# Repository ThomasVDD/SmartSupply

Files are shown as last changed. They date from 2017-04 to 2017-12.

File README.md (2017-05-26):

# SmartSupply
SmartSupply is a digital battery powered lab powersupply. It is Arduino compatible and can be controlled via PC over USB.

## Specifications:
 * 0 - 1A,  steps of 1 mA  (10 bit DAC)
 * 0 - 20V, steps of 20 mV (10 bit DAC) (true 0V operation)
 * Voltage measurement: 20 mV resolution (10 bit ADC)
 * Current measurement: 
      -     < 40mA:  10uA resolution (ina219)
 			< 80mA:  20uA resolution (ina219)
 			< 160mA: 40uA resolution (ina219)
			< 320mA: 80uA resolution (ina219)
			> 320mA: 1mA  resolution (10 bit ADC)

## Features: 
 * Constant voltage and constant current modes
 * Uses a low noise linear regulator, preceded by a tracking preregulator to minimize power dissipation
 * Aluminium case end panel used as heatsink 
 * Use of handsolderable components to keep the project accessible 
 * Powered by ATMEGA328P, programmed with Arduino IDE
 * PC communication via Java application over micro usb
 * Powered by 2 protected 18650 Lithium Ion cells
 * 19 mm spaced banana plugs for compatibility with BNC adapters

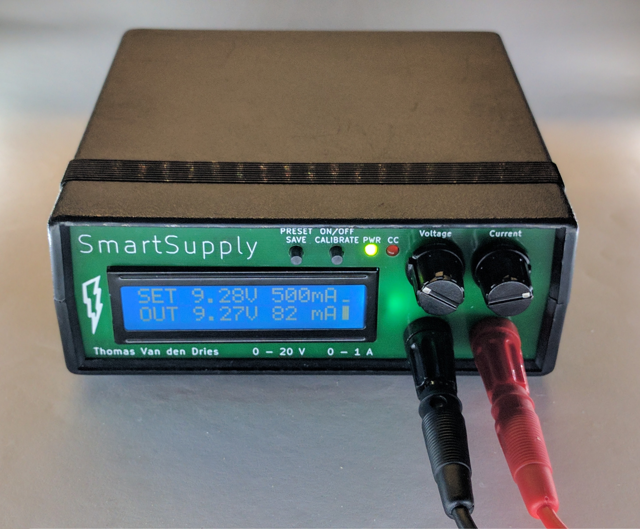
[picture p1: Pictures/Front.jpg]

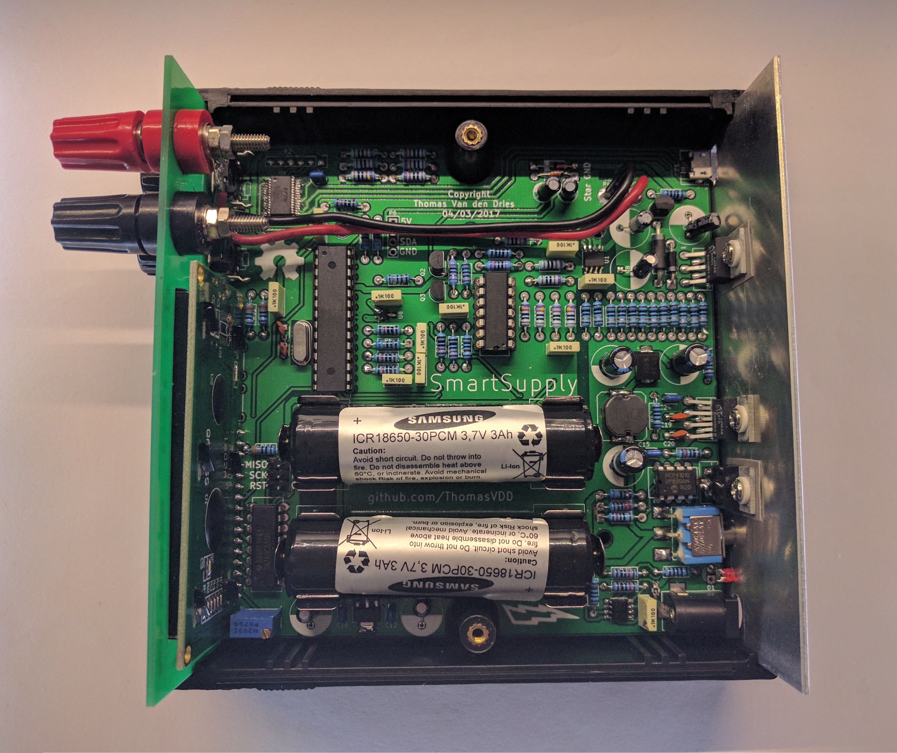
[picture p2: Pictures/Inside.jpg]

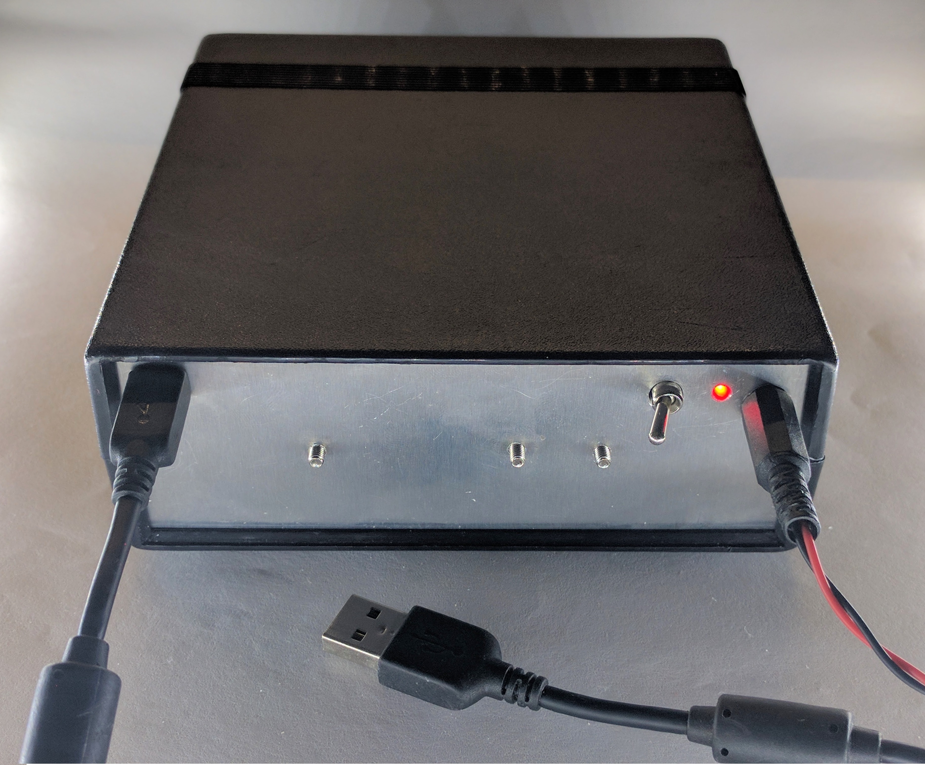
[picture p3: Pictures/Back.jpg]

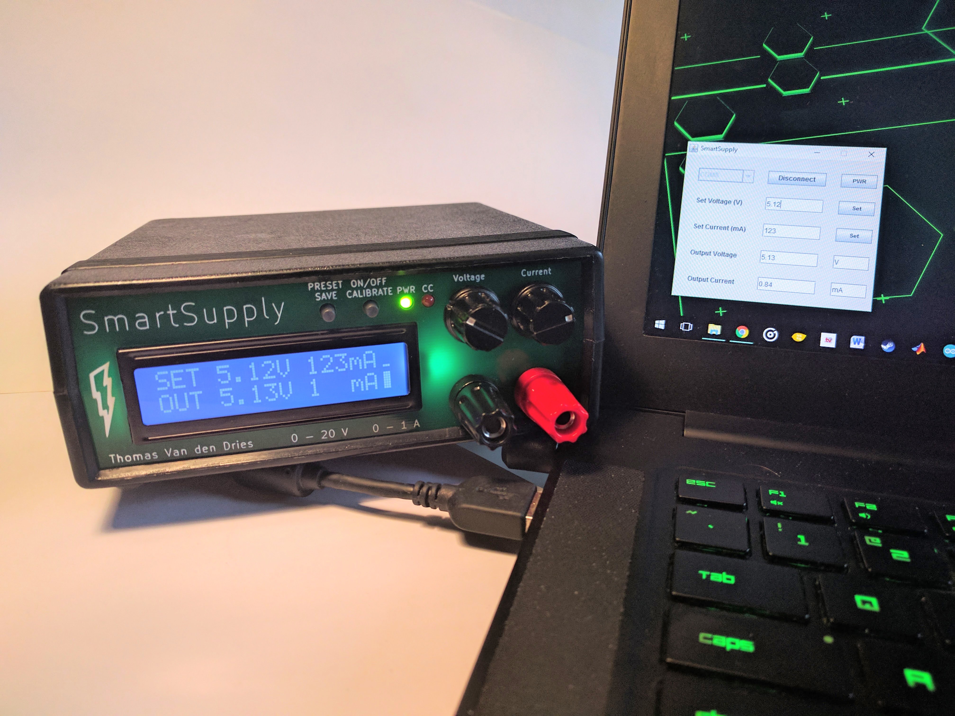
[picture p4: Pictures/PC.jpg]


## Theory of operation: 

To understand the operation of the circuit, we will have to look at the schematic. I divided it into functional blocks, such that it is easier to understand; I will thus also explain the operation step by step. 

### Main block
The operation is based around the LT3080 chip: it's a linear voltage regulator, which can step down voltages, based on a control signal. This control signal will be generated by a microcontroller; how this is done, will be explained in detail later. 

#### Voltage setting
The circuitry around the LT3080 generates the appropriate control signals. First, we will take a look at how the voltage is set. 
The voltage setting from the microcontroller is a PWM signal (PWM_Vset), which is filtered by a lowpass filter (C9 & R26). This produces an analog voltage - between 0 and 5 V - proportional to the wanted output voltage. Since our output range is 0 - 20 V, we will have to amplify this signal with a factor of 4. This is done by the non inverting opamp configuration of U3C. The gain to the set pin is determined by R23//R24//R25 and R34. These resistors are 0.1% tolerant, to minimize errors. R39 and R36 don't matter here, as they are part of the feedback loop.

#### Current setting
This set pin can also be used for the second setting: current mode. We want to measure the current draw, and turn the output off when this exceeds the wanted current. Therefore, we start again by a PWM signal (PWM_Iset), generated by the microcontroller, which is now lowpass filtered and attenuated to go from a 0 - 5 V range to a 0 - 2 V range. This voltage is now compared to the voltage drop across the current sense resistor (ADC_Iout, see below) by the comparator configuration of opamp U3D. If the current is too high, this will turn on an led, and also pull the set line of the LT3080 to ground (via Q2), thus turning off the output.

The measurement of the current, and the generation of the signal ADC_Iout is done as follows. The output current flows through resistors R7 - R16. These total 1 ohm; the reason for not using 1R in the first place is twofold: 1 resistor would need to have a higher power rating (it needs to dissipate at least 1 W), and by using 10 1% resistors in parallel, we get a higher precision than with a single 1 % resistor. A good video about why this works can be found here: https://www.youtube.com/watch?v=1WAhTdWErrU&t=1s
When current flows through these resistors, it creates a voltage drop, which we can measure, and it is placed before the LT3080, since the voltage drop across it should not influence the output voltage. 
The voltage drop is measured with a differential amplifier (U3B) with a gain of 2. This results in a voltage range of 0 - 2 V (more on that later), hence the voltage divider at the PWM signal of the current. The buffer (U3A) is there to make sure that the current flowing into resistors R21, R32 and R33 is not going through the current sense resistor, which would influence it's reading. 
Also note that this should be a rail-to-rail opamp, because the input voltage at the positive input equals the supply voltage. 

The non inverting amplifier is only for the course measurement though, for very precise measurements, we have the INA219 chip on board. This chip allows us to measure very small currents, and is addressed via I2C. 

#### Additional things
At the output of the LT3080, we have some more stuff. First of all, there is a current sink (LM334). This draws a constant current of 677 uA (set by resistor R41), to stabilize the LT3080. It is however not connected to ground, but to VEE, a negative voltage. This is needed to allow the LT3080 to operate down to 0 V. When connected to ground, the lowest voltage would be about 0.7 V. This seems low enough, but keep in mind that this prevents us from turning the powersupply completely off. 
The zener diode D3 is used to clamp the output voltage if it goes above 22 V, and the resistor divider drops the output voltage range from 0 - 20 V to 0 - 2 V (ADC_Vout). 
Unfortunately, these circuits are at the output off the LT3080, which means their current will contribute to the output current we want to measure. Fortunately, these currents are constant if the voltage stays constant; so we can calibrate the current when the load is disconnected first. 

### Charge pump
The negative voltage that we mentioned before is generated by a curious little circuit: the charge pump. For it's operation, I would refer to here: https://www.youtube.com/watch?v=LtoPHevexTM&t=2s It is fed by a 50% PWM of the microcontroller (PWM)

### Boost Converter
Let's now take a look at the input voltage of our main block: Vboost. We see that it is 8 - 24V, but wait, 2 lithium cells in series gives a maximum of 8.4 V? Indeed, and that's why we need to boost the voltage, with a so called boost converter. We could always boost the voltage to 24 V, no matter what output we want; however, this would waste a lot of power in the LT3080 and things would get toasty hot! So instead of doing that, we will boost the voltage to a bit more than the output voltage. About 2.5 V higher is appropriate, to account for the voltage drop in the current sense resistor and the dropout voltage of the LT3080. 
The voltage is set by resistors on the output signal of the boost converter. To change this voltage on the fly, we use a digital potentiometer, the MCP41010, which is controlled via SPI. 

### Battery Charging
This leads us to the real input voltage: the batteries! Since we use protected cells, we simply need to put them in series and we're done! It is important to use protected cells here, to avoid overcurrent or overdischarge, and thus damaging, of the cells. 
Again, we use a voltage divider for measuring the battery voltage, and dropping it down to a usable range.
Now on to the interesting part: the charging circuitry. We use the BQ2057WSN chip for this purpose: in combination with the TIP32CG, it basically forms a linear powersupply itself. This chip charges the cells via an appropriate CV CC trajectory. Since my batteries don't have a temperature probe, this input should be tied to half the battery voltage. This concludes the voltage regulation part of the powersupply. 

### 5V regulator
The 5 V supply voltage of the arduino is made with this simple voltage regulator. It is not the most precise 5 V output however, but this will be solved below. 

### 2.048 V voltage reference
This little chip provides a very accurate 2.048 V voltage reference. This is used as a reference for the analog signals ADC_Vout, ADC_Iout, ADC_Vbatt. That's why we needed voltage dividers to bring these signals down to 2 V. 

### Microcontroller
The brain of this project is the ATMEGA328P, this is the same chip that is used in the Arduino Uno. We already went over most control signals, but there are some interesting additions nonetheless. The rotary encoders are connected to the 2 only external interrupt pins of the arduino: PD2 and PD3. This is needed for a reliable software implementation. The switches underneath use an internal pullup resistor. 
Then there is this strange voltage divider on the chip select line of the potentiometer (Pot). A voltage divider on an output, what's that good for; you might say. As mentioned before, the 5 V supply is not teribbly accurate. It would thus be good to measure this accurately, and adjust the duty cycle of the PWM signal accordingly. But since I had no more free inputs, I had to make a pin pull double duty. When the powersupply boots, this pin is first set as an input: it measures the supply rail and calibrates itself. Next, it is set as an output and it can drive the chip select line. 

### Display Driver
For the display, I wanted a commonly available - and cheap - hitachi lcd screen. They are driven by 6 pins, but since I had no pins left, I needed another solution. A shift register to the rescue! The 74HC595 allows me to use the SPI line to control the display, thus only needing 1 additional chip select line. 

### FTDI
The last part of this powersupply is the connection with the cruel, outside world. For this, we need to convert the serial signals into USB signals. This is done by an FTDI chip, which is connected to a micro USB port for easy connection.

And that's all there is to it! 

## Licensing and acknowledgements

License

This project would never have been possible without the help of some people, so a shootout seems appropriate.
 * This project is based on EEVBLOG's uSupply project and his Rev C schematic. So a special thanks to David L. Jones for releasing his schematics under an open source license and sharing all his knowledge.
 * A huge thanks to Johan Pattyn for producing the prototypes of this project. 
 * Also Cedric Busschots and Hans Ingelberts deserve credit for the help with troubleshooting.

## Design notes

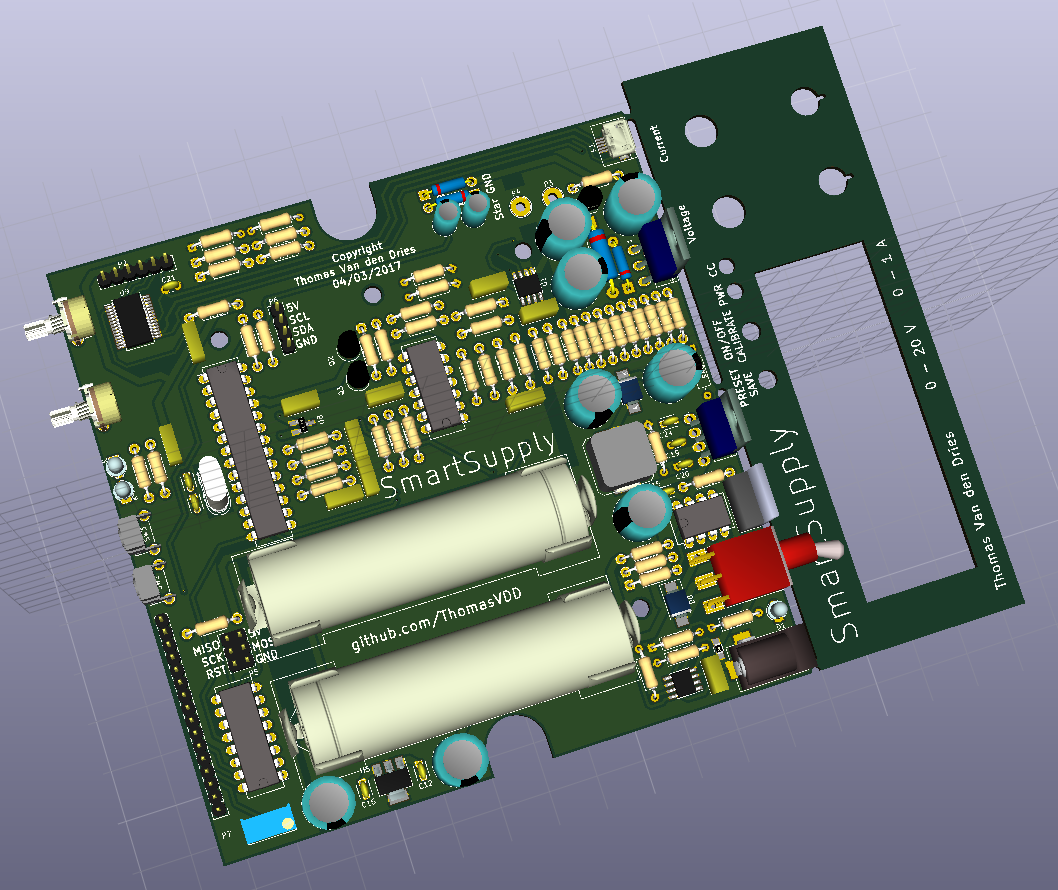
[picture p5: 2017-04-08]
Pictures/3D.PNG

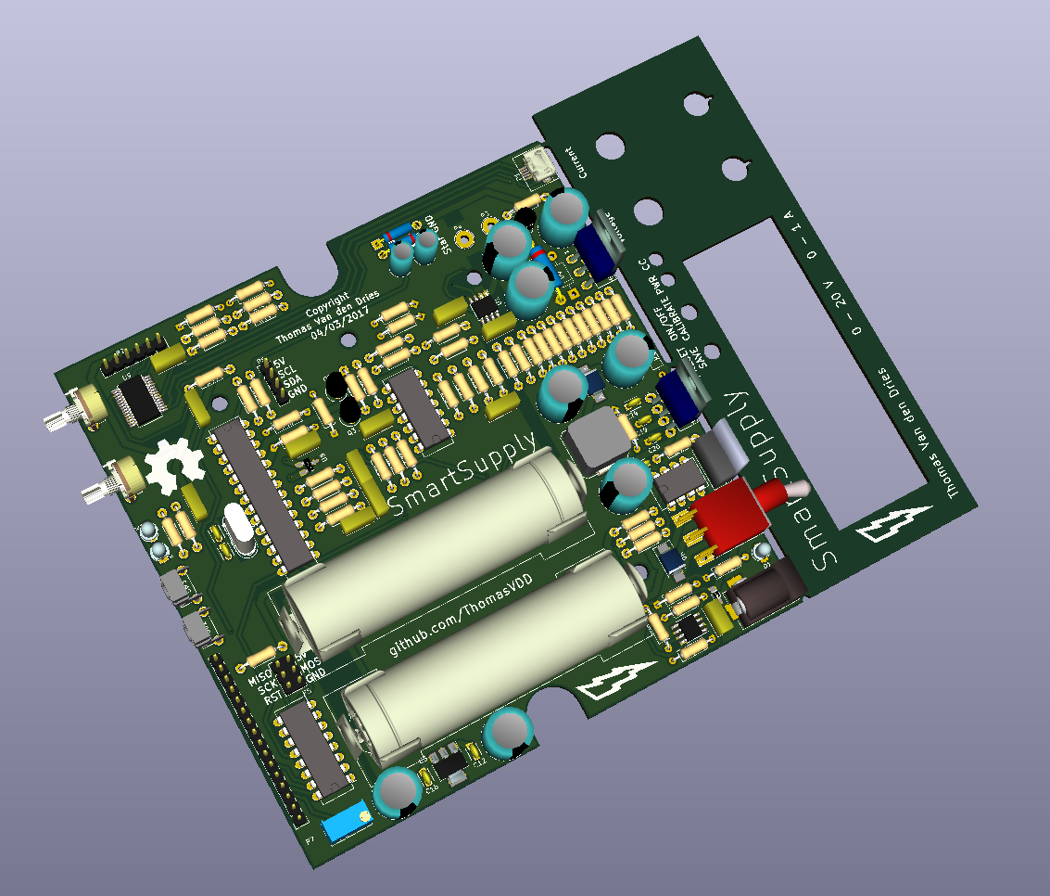
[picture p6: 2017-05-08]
PCB/3D.PNG

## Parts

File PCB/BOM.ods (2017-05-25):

Id | Designator | Package | Quantity | Designation | Supplier and ref | Price | Total | No_Battery | No_battery | Aliexpress
1 | R1,R2,R7,R8,R9,R10,R11,R12,R13,R14,R15,R16 | Resistor_Horizontal_RM10mm | 12 | 10R |  |  | 0 | 1 | 0
2 | R6,R18,R31,R36,R42 | Resistor_Horizontal_RM10mm | 5 | 1k |  |  | 0 | 1 | 0
3 | R27,R5,R53,R54 | Resistor_Horizontal_RM10mm | 4 | 6k8 |  |  | 0 | 1 | 0
4 | R28,R48 | Resistor_Horizontal_RM10mm | 2 | 2.2k |  |  | 0 | 1 | 0
5 | R3,R17,R19,R20,R26,R35,R37,R38,R51,R55 | Resistor_Horizontal_RM10mm | 10 | 10k |  |  | 0 | 1 | 0
6 | R52,R56,R40 | Resistor_Horizontal_RM10mm | 3 | 330R |  |  | 0 | 1 | 0
7 | R39,R41 | Resistor_Horizontal_RM10mm | 2 | 100R |  |  | 0 | 1 | 0
8 | R50 | Resistor_Horizontal_RM10mm | 1 | 620R |  |  | 0 | 1 | 0
9 | R34,R21,R22,R25,R29,R30,R32,R33,R43,R44,R45,R47,R23,R24,R46,R49, R57, R58, R59 | Resistor_Horizontal_RM10mm | 19 | 10k 0.1% | 1083362 | 0.711 | 13.509 | 1 | 13.509 | 7
10 | R4 | R_0805_HandSoldering | 1 | 0.2R | 2493030 | 0.335 | 0.335 | 0 | 0 | 0.335
11 | RV1 | Potentiometer_Bourns_3296W_3-8Zoll_Inline_ScrewUp | 1 | POT | 1141404 | 1.49 | 1.49 | 1 | 1.49 | 0.1
12 | C1,C3,C6,C7,C9,C22,C29,C2,C5,C10,C21,C23 | C_Rect_L7_W2.5_P5 | 12 | 100n |  |  | 0 | 1 | 0
13 | C13,C4,C25 | C_Radial_D10_L13_P5 | 3 | 220u |  |  | 0 | 1 | 0
14 | C24,C15,C12,C16 | C_Disc_D3_P2.5 | 4 | 10n |  |  | 0 | 1 | 0
16 | C26,C27 | C_Disc_D3_P2.5 | 2 | 22p |  |  | 0 | 1 | 0
17 | C14,C11,C18 | C_Radial_D10_L13_P5 | 5 | 22u |  |  | 0 | 1 | 0
18 | C30 | C_Radial_D5_L11_P2.5 | 1 | 100u |  |  | 0 | 1 | 0
19 | C28 | C_Radial_D5_L11_P2.5 | 1 | 22u |  |  | 0 | 1 | 0
20 | C19 | C_Disc_D3.0mm_W1.6mm_P2.50mm | 1 | 47n |  |  | 0 | 1 | 0
21 | C20 | C_Disc_D3.0mm_W1.6mm_P2.50mm | 1 | 4.7n |  |  | 0 | 1 | 0
22 | L1 | SELF-WE-PD-XXL | 1 | 47u | 1864422 | 0.778 | 0.778 | 1 | 0.778 | 0.94138
23 | D1, D2 | LED-3MM | 2 | Red_Led |  |  | 0 | 0 | 0
24 | D3 | D_DO-41_SOD81_P10.16mm_Horizontal | 1 | 1N5358B | 9558160 | 0.381 | 0.381 | 1 | 0.381 | 0.46101
25 | D4,D8 | SMB_Handsoldering | 2 | SS34 | 2677460 | 0.25 | 0.5 | 0 | 0 | 0.5
26 | D5 | LED-3MM | 1 | Green_Led |  |  | 0 | 1 | 0
27 | D6,D7 | Diode_DO-41_SOD81_Horizontal_RM10 | 2 | 1N4148 | 9565124 | 0.0203 | 0.0406 | 1 | 0.0406 | 0.049126
28 | D9 | D_DO-41_SOD81_P10.16mm_Horizontal | 1 | 1N4007 | 1467514 | 0.169 | 0.169 | 1 | 0.169 | 0.20449
29 | U1 | SOIC-8_3.9x4.9mm_Pitch1.27mm | 1 | INA219 | 2496402 | 2.45 | 2.45 | 1 | 2.45 | 2.9645
30 | U2 | SOIC-8_3.9x4.9mm_Pitch1.27mm | 1 | BQ2057WSN_SOIC | 1212263 | 2.2 | 2.2 | 0 | 0 | 1
31 | U3 | DIP-14_W7.62mm_LongPads | 1 | LM6144 | 9493581 | 5.56 | 5.56 | 1 | 5.56 | 6.7276
32 | U4 | Pentawatt_Neutral_Staggered_Verical_TO220-5-T05D | 1 | LT3080 | 2102611 | 4.52 | 4.52 | 1 | 4.52 | 4.52
33 | U5 | SOT-223-3Lead_TabPin2 | 1 | LM7805CT | 2296030 | 0.291 | 0.291 | 1 | 0.291 | 0.291
34 | U6 | TO-92_Inline_Narrow_Oval | 1 | LM334 | 1564650 | 0.784 | 0.784 | 1 | 0.784 | 0.94864
35 | U7 | Pentawatt_Neutral_Staggered_Verical_TO220-5-T05D | 1 | LT1370 | 1273732 | 10.94 | 10.94 | 1 | 10.94 | 2
36 | U8 | SOT-23_Handsoldering | 1 | ISL21070 | 2543327 | 1.57 | 1.57 | 1 | 1.57 | 1.8997
37 | U9 | SSOP-28_5.3x10.2mm_Pitch0.65mm | 1 | FT232R | 1146032 | 4.25 | 4.25 | 1 | 4.25 | 2
38 | U10 | DIP-8_W7.62mm_LongPads | 1 | MCP41010 | 1292242 | 1.28 | 1.28 | 1 | 1.28 | 0.7
39 | U11 | DIP-16_W7.62mm_LongPads | 1 | 74HC595 | 9591664 | 1.18 | 1.18 | 1 | 1.18 | 0.5
40 | IC1 | DIP-28_W7.62mm_LongPads | 1 | ATMEGA328-P | 1715487 | 3.36 | 3.36 | 1 | 3.36 | 1.1
41 | Q1 | SOT-223-3Lead_TabPin2 | 1 | TIP32CG | 1166986 | 0.446 | 0.446 | 0 | 0 | 0.446
42 | Q2,Q3 | TO-92_Inline_Narrow_Oval | 2 | 2N3904 | 1700648 | 0.0762 | 0.1524 | 1 | 0.1524 | 0.1524
43 | P1 | Micro_usb | 1 | USB_OTG | 2293753 | 0.413 | 0.413 | 1 | 0.413 | 0.413
44 | P2 | Pin_Header_Straight_1x06 | 1 | FTDI |  |  | 0 | 1 | 0
45 | P3 | 1pin | 1 | V+ | 2112491 | 2.85 | 2.85 | 1 | 2.85 | 0.5
46 | P4 | 1pin | 1 | V- | 2112490 | 2.85 | 2.85 | 1 | 2.85 | 0.5
47 | P5 | Pin_Header_Straight_2x03 | 1 | ISP |  |  | 0 | 1 | 0
48 | P6 | Pin_Header_Straight_1x04 | 1 | I2C |  |  | 0 | 1 | 0
49 | P7 | Pin_Header_Straight_1x16 | 1 | LCD_Display | aliexpress: https://nl.aliexpress.com/item/Free-shipping-lcd-1602-yellow-green-screen-5V-Character-LCD-Display-Module-yellow-green-Blacklight-New/32333016122.html | 1.12 | 1.12 | 1 | 1.12 | 1.12
50 | SW1 | SW_SPDT | 1 | SWITCH | aliexpress: https://nl.aliexpress.com/item/10-Pcs-2A-250VAC-on-on-2-Way-SPDT-Right-Angle-3-Pins-PCB-Mount-Toggle/32284524869.html | 1.85 | 1.85 | 1 | 1.85 | 1.85
51 | SW2,SW3 | SW_Tactile_SPST_Angled | 2 | SPST | 2402408 | 0.586 | 1.172 | 1 | 1.172 | 0.5
52 | SW4 | Potentiometer_WirePads_Small | 1 | Encoder1 | 2065049 | 0.575 | 0.575 | 1 | 0.575 | 0.69575
53 | SW5 | Potentiometer_WirePads_Small | 1 | Encoder0 | 2065049 | 0.575 | 0.575 | 1 | 0.575 | 0.69575
54 | Y1 | Crystal_HC50-U_Vertical | 1 | 16Mhz | 2508996 | 0.261 | 0.261 | 1 | 0.261 | 0.261
55 | BT2,BT1 | 18650_cell | 4 | Battery | 1888422 | 0.73 | 2.92 | 0 | 0 | 3.5332
56 | CON1 | BARREL_JACK | 1 | BARREL_JACK | 1737246 | 0.789 | 0.789 | 1 | 0.789 | 0.789
 |  | Thermal pad + mica washer | 2 |  | 520214 | 0.231 | 0.462 | 1 | 0.462 | 0.462
 |  | Hammond case with aluminium end panels | 1 |  | 722583 | 12.17 | 12.17 | 1 | 12.17 | 14.7257
 |  | Knobs for rotary encoders | 2 |  | atys | 1.5 | 3 | 1 | 3 | 1
 |  | Protected Lithium cells | 2 |  | http://www.conrad.be/ce/nl/product/1009505/Samsung-ICR18650-30B-Speciale-oplaadbare-batterij-18650-Li-ion-37-V-3000-mAh | 14.79 | 29.58 | 0 | 0 | 29.58
 |  |  |  |  |  |  | Battery |  | No Battery | Aliexpress
 |  |  |  |  |  |  | Total |  | Total | Total
 |  |  |  |  |  |  | 134.45353 |  | 97.12832 | 91.466246

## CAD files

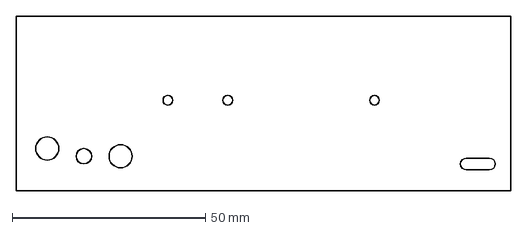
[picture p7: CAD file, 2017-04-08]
BackPanel/BackPanel.dxf
128.0 x 45.3 mm

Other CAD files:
BackPanel/BackPanel.ipt
BackPanel/OldVersions/BackPanel.0002.ipt

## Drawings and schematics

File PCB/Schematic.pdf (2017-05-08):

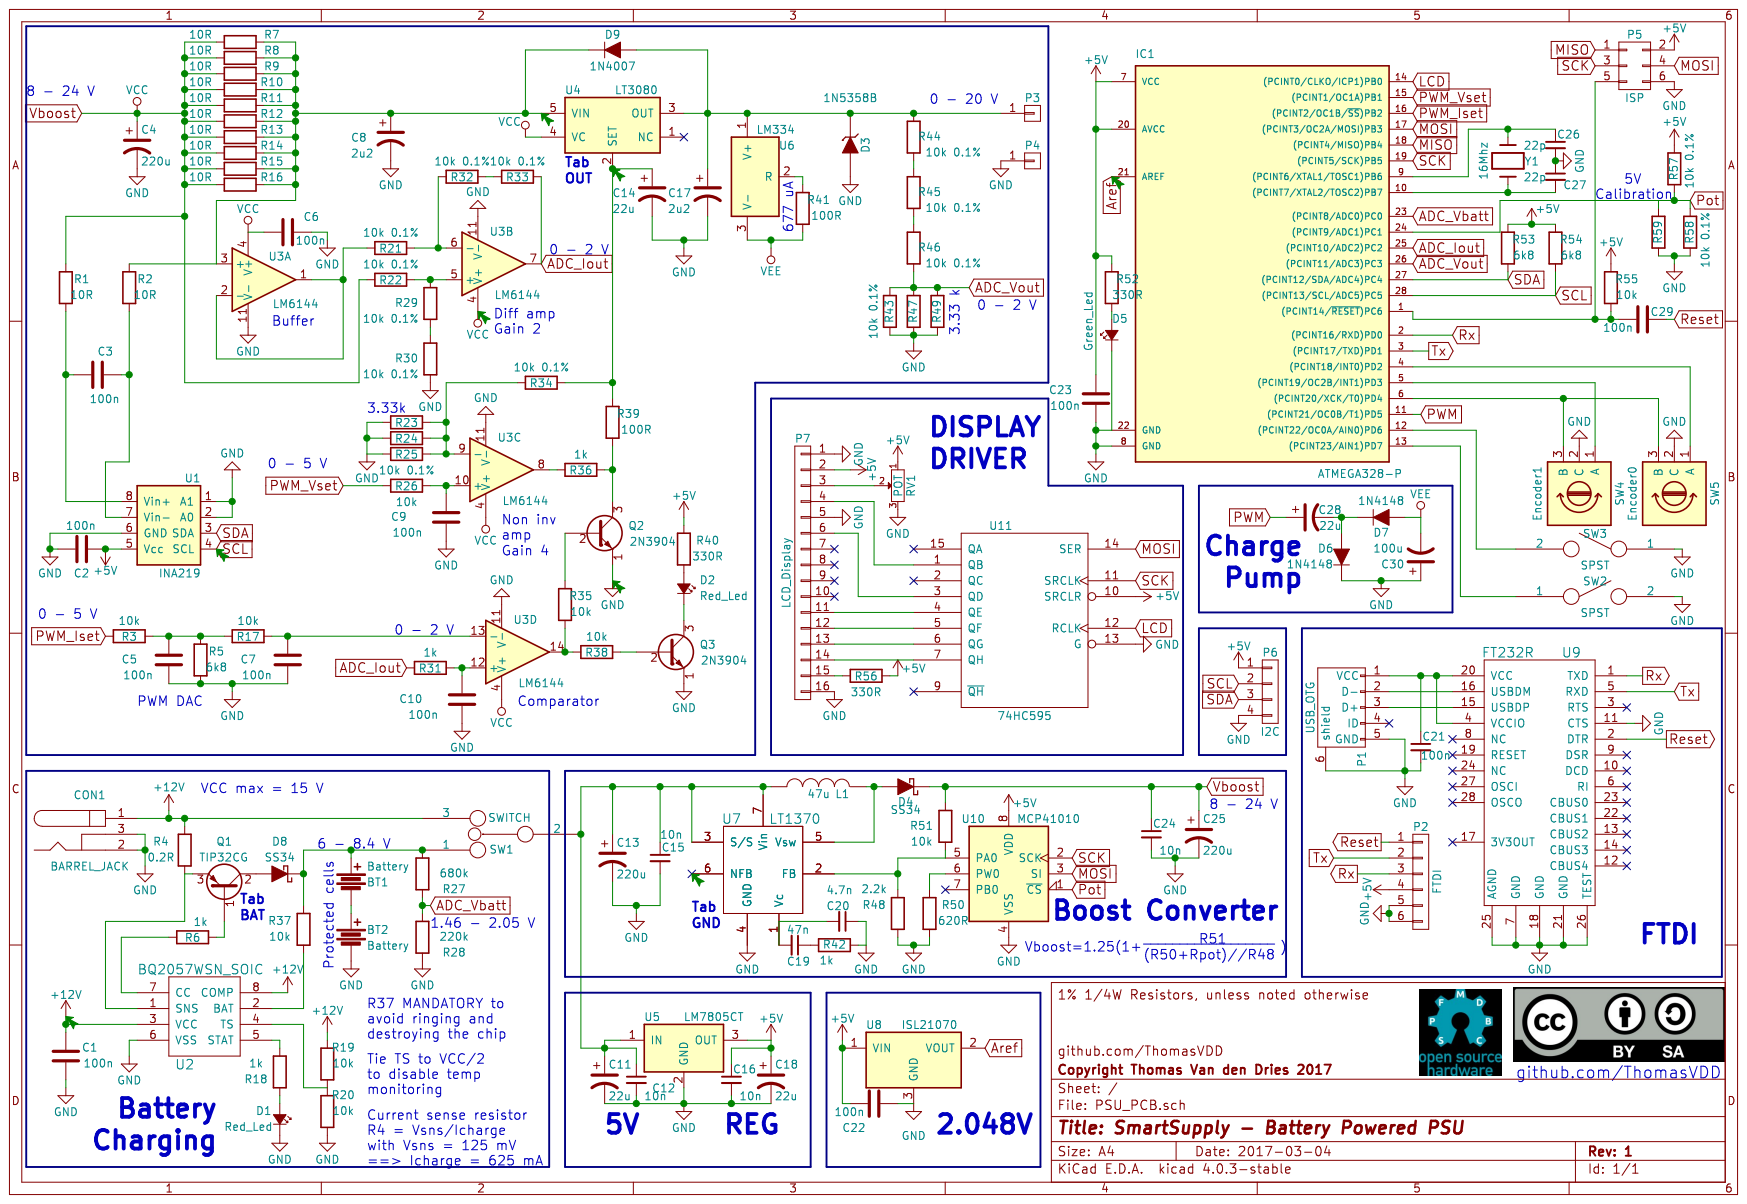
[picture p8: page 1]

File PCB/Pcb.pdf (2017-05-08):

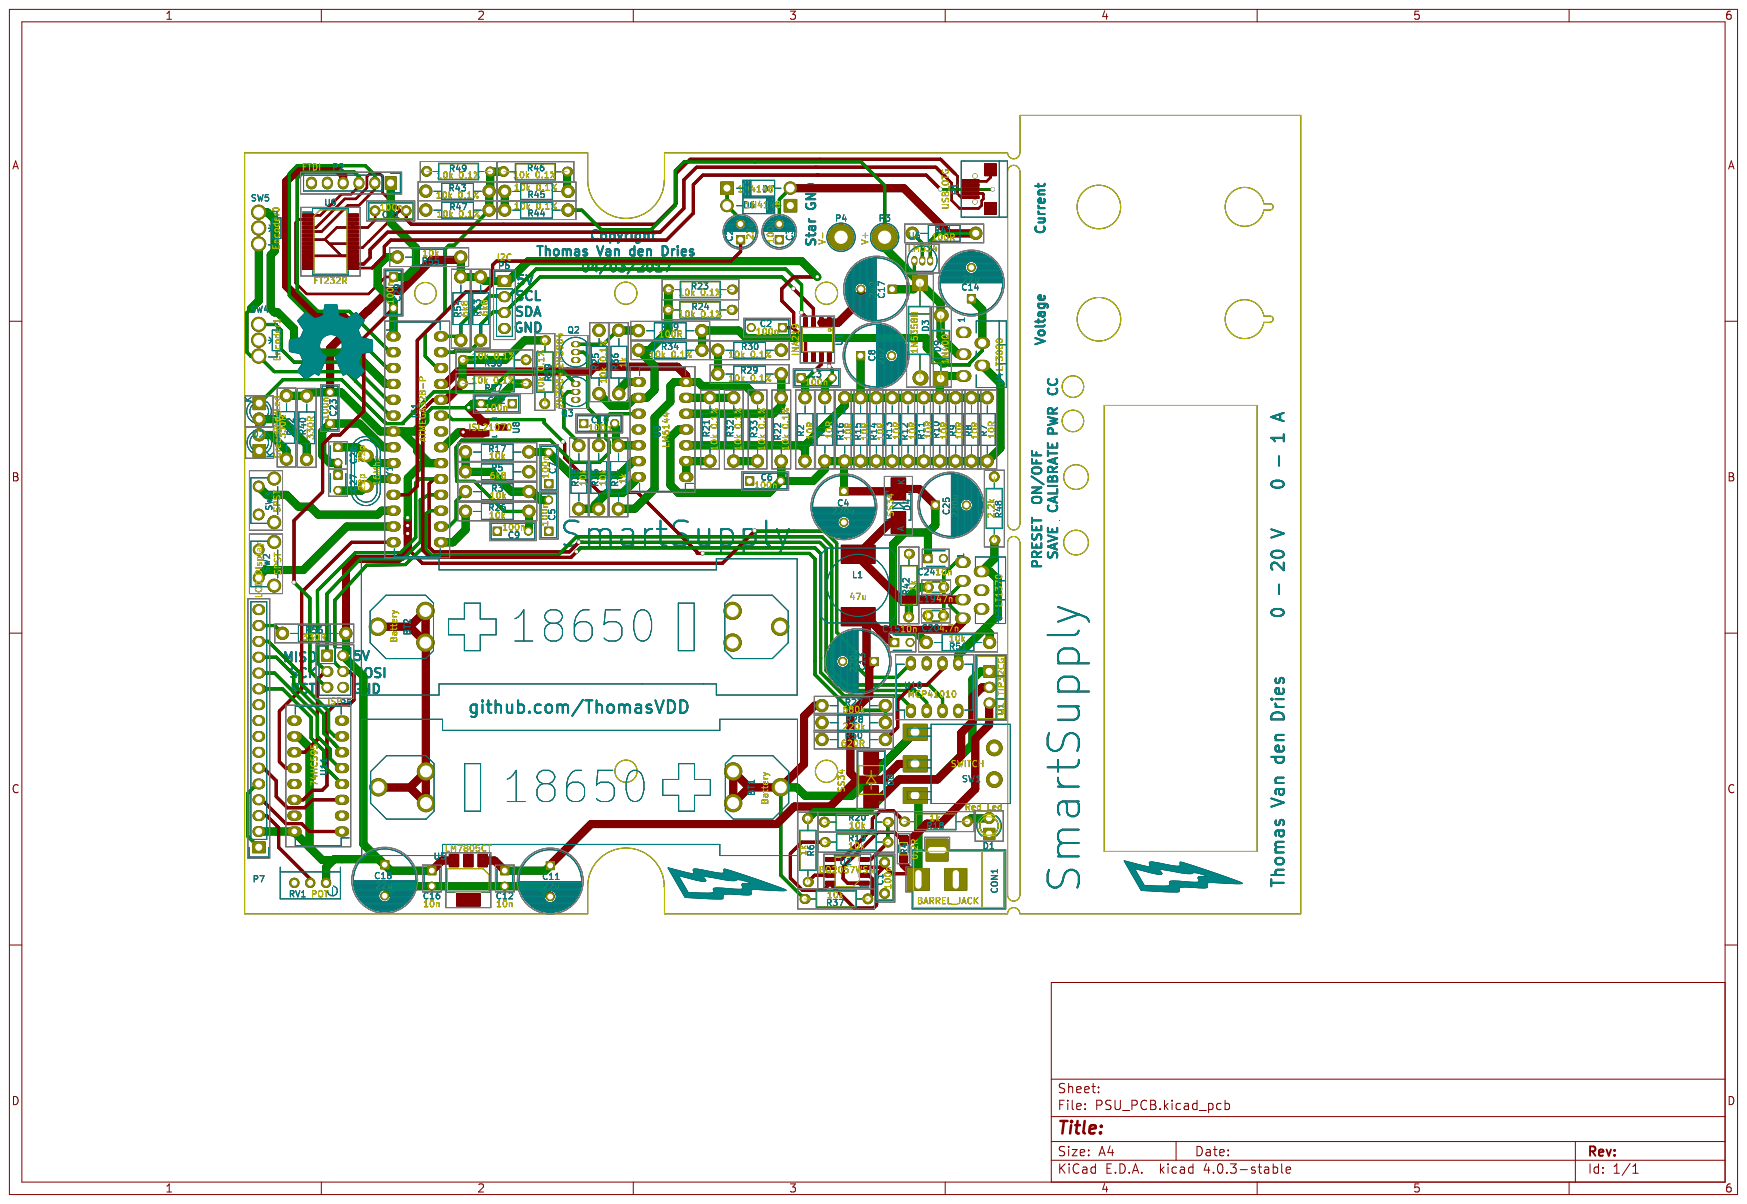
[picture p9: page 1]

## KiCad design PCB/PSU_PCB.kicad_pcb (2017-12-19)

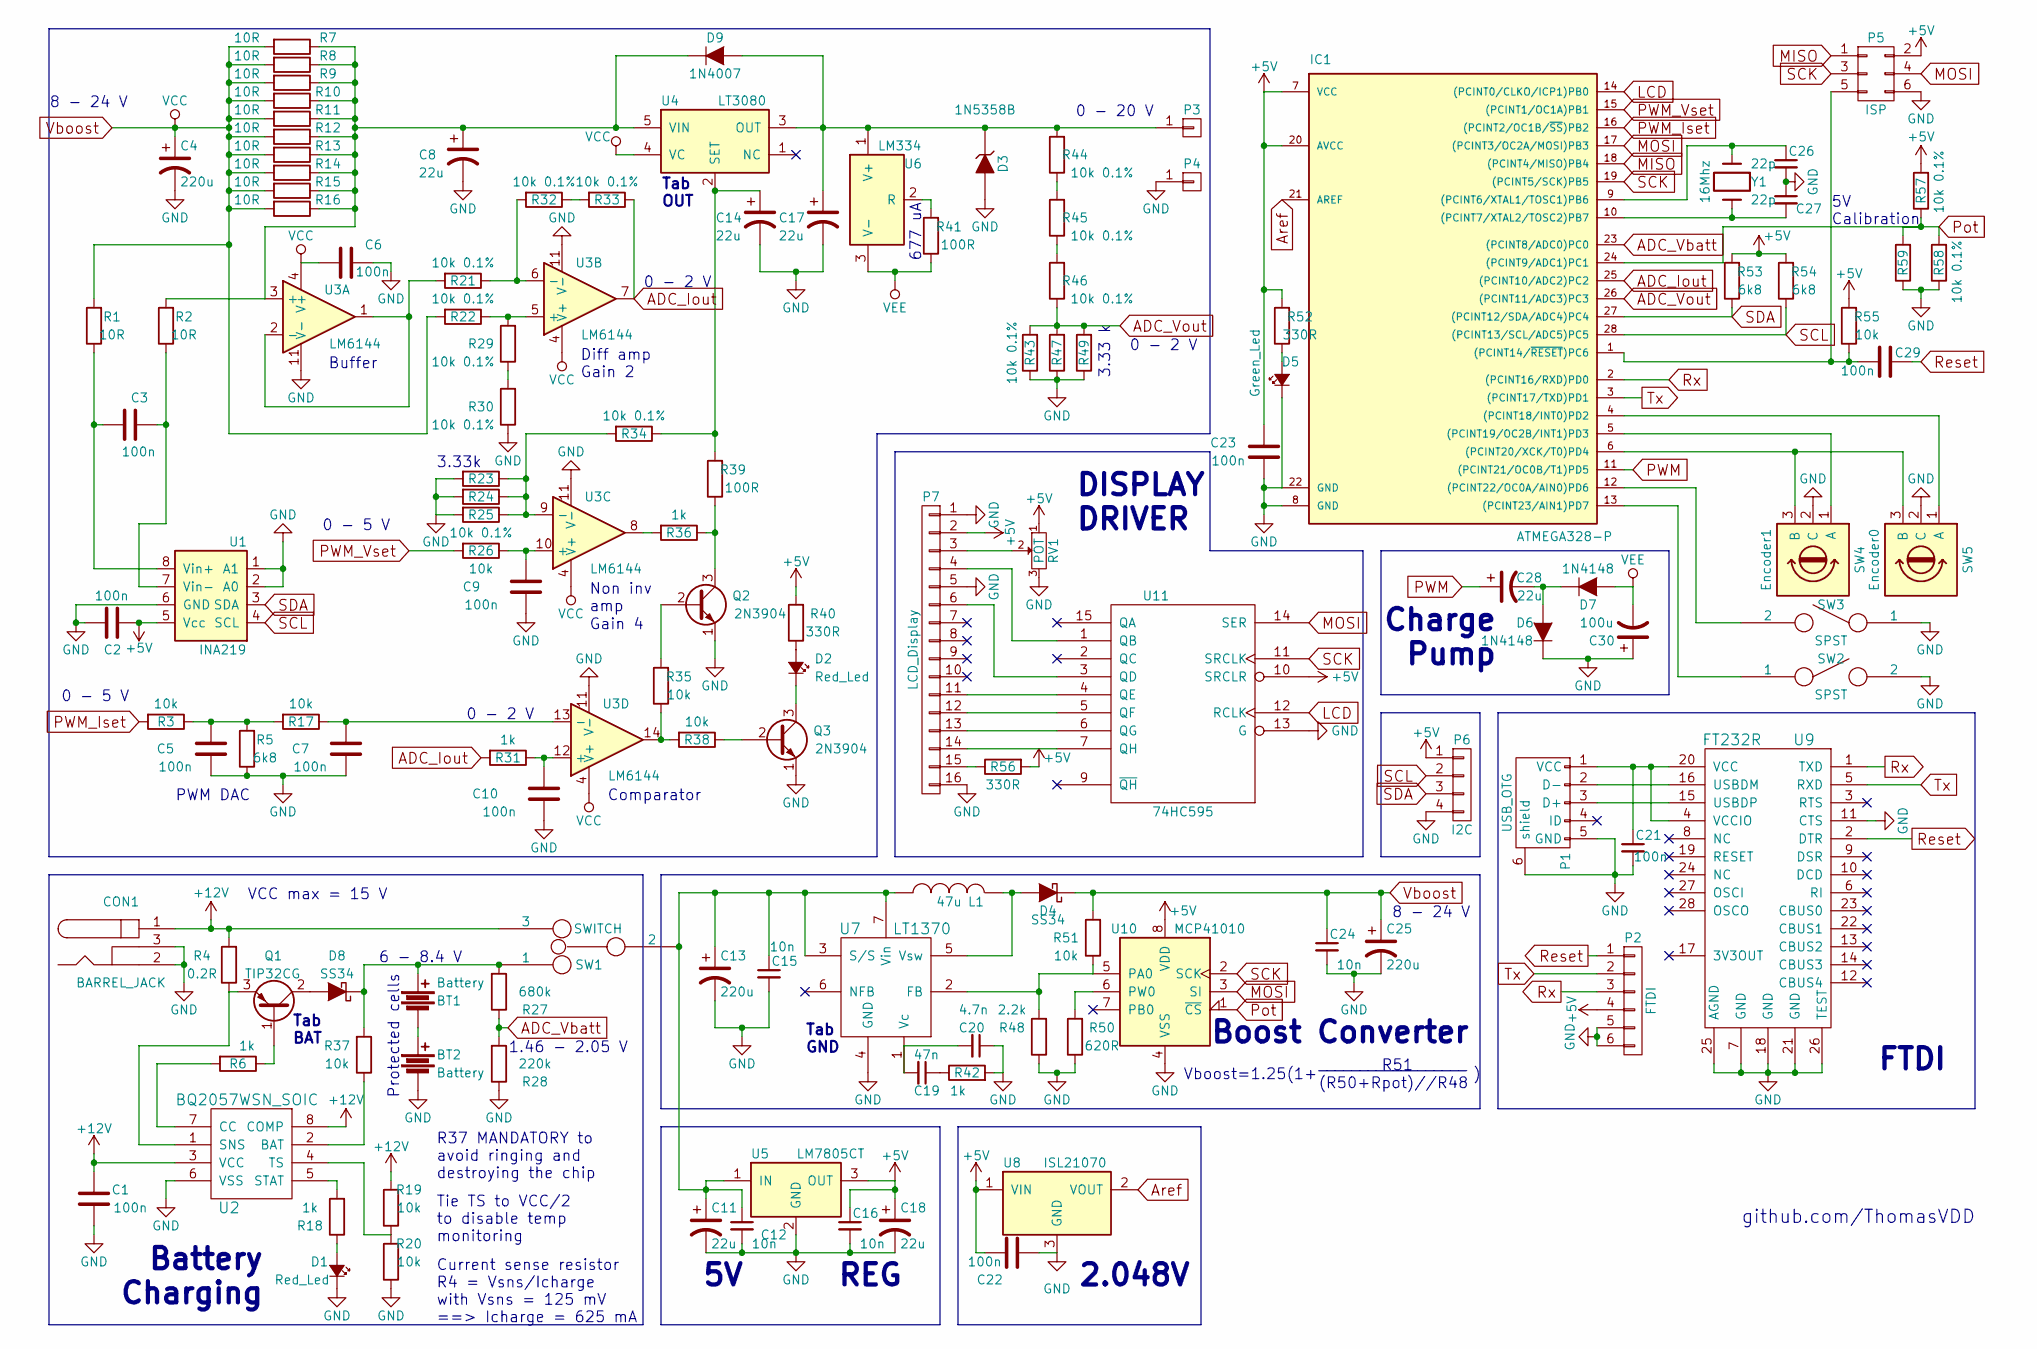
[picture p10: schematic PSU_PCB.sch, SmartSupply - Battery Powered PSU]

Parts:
BT1, BT2: Battery; 18650_cell
C1, C21: 100n; C_Rect_L7.0mm_W2.5mm_P5.00mm
C2, C3, C5, C6, C7, C9, C10, C22, C23, C29: 100n; C_Rect_L7_W2.5_P5
C4, C13, C25: 220u; C_Radial_D10_L13_P5
C8, C11, C14, C17, C18: 22u; C_Radial_D10_L13_P5
C12, C15, C16, C24: 10n; C_Disc_D3_P2.5
C19: 47n; C_Disc_D3.0mm_W1.6mm_P2.50mm
C20: 4.7n; C_Disc_D3.0mm_W1.6mm_P2.50mm
C26, C27: 22p; C_Disc_D3_P2.5
C28: 22u; C_Radial_D5_L11_P2.5
C30: 100u; C_Radial_D5_L11_P2.5
CON1: BARREL_JACK
D1: Red_Led; LED_D3.0mm
D2: Red_Led; LED-3MM
D3: 1N5358B; D_DO-15_P15.24mm_Horizontal
D4: SS34; SMB_Handsoldering
D5: Green_Led; LED-3MM
D6, D7: 1N4148; Diode_DO-41_SOD81_Horizontal_RM10
D8: SS34; D_SMB_Handsoldering
D9: 1N4007; D_DO-41_SOD81_P10.16mm_Horizontal
IC1: ATMEGA328-P; DIP-28_W7.62mm_LongPads
L1: 47u; SELF-WE-PD-XXL
P1: USB_OTG; Micro_usb
P2: FTDI; Pin_Header_Straight_1x06
P3: V+; 1pin
P4: V-; 1pin
P5: ISP; Pin_Header_Straight_2x03
P6: I2C; Pin_Header_Straight_1x04
P7: LCD_Display; Pin_Header_Straight_1x16
Q1: TIP32CG; TO-220_Vertical
Q2, Q3: 2N3904; TO-92_Inline_Narrow_Oval
R1, R2, R7, R8, R9, R10, R11, R12, R13, R14, R15, R16: 10R; Resistor_Horizontal_RM10mm
R3, R17, R26, R35, R38, R51, R55: 10k; Resistor_Horizontal_RM10mm
R4: 0.2R; R_0805_HandSoldering
R5, R53, R54: 6k8; Resistor_Horizontal_RM10mm
R6, R18, R42: 1k; R_Axial_DIN0207_L6.3mm_D2.5mm_P10.16mm_Horizontal
R19, R20, R37: 10k; R_Axial_DIN0207_L6.3mm_D2.5mm_P10.16mm_Horizontal
R21, R22, R25, R29, R30, R32, R33, R34, R43, R44, R45, R47: 10k 0.1%; Resistor_Horizontal_RM10mm
R23, R24, R46, R49, R57, R58, R59: 10k 0.1%; R_Axial_DIN0207_L6.3mm_D2.5mm_P10.16mm_Horizontal
R27: 680k; Resistor_Horizontal_RM10mm
R28: 220k; Resistor_Horizontal_RM10mm
R31, R36: 1k; Resistor_Horizontal_RM10mm
R39, R41: 100R; Resistor_Horizontal_RM10mm
R40, R52, R56: 330R; Resistor_Horizontal_RM10mm
R48: 2.2k; R_Axial_DIN0207_L6.3mm_D2.5mm_P10.16mm_Horizontal
R50: 620R; Resistor_Horizontal_RM10mm
RV1: POT; Potentiometer_Bourns_3296W_3-8Zoll_Inline_ScrewUp
SW1: SWITCH; SW_SPDT
SW2, SW3: SPST; SW_Tactile_SPST_Angled
SW4: Encoder1; Potentiometer_WirePads_Small
SW5: Encoder0; Potentiometer_WirePads_Small
U1: INA219; SOIC-8_3.9x4.9mm_Pitch1.27mm
U2: BQ2057WSN_SOIC; SOIC-8_3.9x4.9mm_Pitch1.27mm
U3: LM6144; DIP-14_W7.62mm_LongPads
U4: LT3080; Pentawatt_Neutral_Staggered_Verical_TO220-5-T05D
U5: LM7805CT; SOT-223-3Lead_TabPin2
U6: LM334; TO-92_Inline_Narrow_Oval
U7: LT1370; Pentawatt_Neutral_Staggered_Verical_TO220-5-T05D
U8: ISL21070; SOT-23_Handsoldering
U9: FT232R; SSOP-28_5.3x10.2mm_Pitch0.65mm
U10: MCP41010; DIP-8_W7.62mm_LongPads
U11: 74HC595; DIP-16_W7.62mm_LongPads
Y1: 16Mhz; Crystal_HC50-U_Vertical

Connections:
+5V: C2.1, C16.1, C18.1, C22.2, C23.2, IC1.7 (VCC), IC1.20 (AVCC), P2.4, P5.2, P6.1, P7.2, R40.2, R52.2, R53.2, R54.2, R55.2, R56.2, R57.2, RV1.1, U1.5 (Vcc), U5.3 (OUT), U8.1 (VIN), U10.8 (VDD), U11.10 (SRCLR), U11.16 (+5V)
+12V: C1.2, CON1.1, R4.2, R19.2, SW1.3, U2.3 (VCC), U2.8 (COMP)
ADC_Iout: IC1.25 ((PCINT10/ADC2)PC2), R31.2, R33.1, U3.7
ADC_Vbatt: IC1.23 ((PCINT8/ADC0)PC0), R27.1, R28.2
ADC_Vout: IC1.26 ((PCINT11/ADC3)PC3), R43.2, R46.1, R47.2, R49.2
Aref: IC1.21 (AREF), U8.2 (VOUT)
GND: BT2.2, C1.1, C2.2, C4.2, C5.1, C6.1, C7.1, C8.2, C9.1, C10.1, C11.2, C12.2, C13.2, C14.2, C15.2, C16.2, C17.2, C18.2, C20.1, C21.2, C22.1, C23.1, C24.2, C25.2, C26.2, C27.1, C30.1, CON1.2, CON1.3, D1.1 (K), D3.2 (A), D5.1 (K), D6.1 (K), IC1.8 (GND), IC1.22 (GND), P1.5 (GND), P1.6 (shield), P2.5, P2.6, P4.1, P5.6, P6.4, P7.1, P7.5, P7.16, Q2.1 (E), Q3.1 (E), R5.1, R20.1, R23.2, R24.2, R25.2, R28.1, R30.1, R42.2, R43.1, R47.1, R48.1, R49.1, R50.1, R58.1, R59.1, RV1.3, SW2.2, SW3.1, SW4.2 (C), SW5.2 (C), U1.1 (A1), U1.2 (A0), U1.6 (GND), U2.6 (VSS), U3.11 (V-), U5.2 (GND), U7.4 (GND), U8.3 (GND), U9.7 (GND), U9.11 (CTS), U9.18 (GND), U9.21 (GND), U9.25 (AGND), U9.26 (TEST), U10.4 (VSS), U11.8 (GND), U11.13 (G)
LCD: IC1.14 ((PCINT0/CLKO/ICP1)PB0), U11.12 (RCLK)
MISO: IC1.18 ((PCINT4/MISO)PB4), P5.1
MOSI: IC1.17 ((PCINT3/OC2A/MOSI)PB3), P5.4, U10.3 (SI), U11.14 (SER)
unnamed: BT1.1, D8.1 (K), R27.2, R37.2, SW1.1
unnamed: BT1.2, BT2.1
unnamed: C3.1, R2.1, U1.7 (Vin-)
unnamed: C3.2, R1.1, U1.8 (Vin+)
unnamed: C5.2, R3.1, R5.2, R17.2
unnamed: C7.2, R17.1, U3.13 (-)
unnamed: C8.1, D9.1 (K), R2.2, R7.1, R8.1, R9.1, R10.1, R11.1, R12.1, R13.1, R14.1, R15.1, R16.1, U3.3 (+), U4.5 (VIN)
unnamed: C9.2, R26.1, U3.10 (+)
unnamed: C10.2, R31.1, U3.12 (+)
unnamed: C11.1, C12.1, C13.1, C15.1, L1.2, SW1.2, U5.1 (IN), U7.3 (S/S), U7.7 (Vin)
unnamed: C14.1, R34.1, R39.2, U4.2 (SET)
unnamed: C17.1, D3.1 (K), D9.2 (A), P3.1, R44.2, U4.3 (OUT), U6.1 (V+)
unnamed: C19.1, R42.1
unnamed: C19.2, C20.2, U7.1 (Vc)
unnamed: C21.1, P1.1 (VCC), U9.4 (VCCIO), U9.20 (VCC)
unnamed: C26.1, IC1.9 ((PCINT6/XTAL1/TOSC1)PB6), Y1.1
unnamed: C27.2, IC1.10 ((PCINT7/XTAL2/TOSC2)PB7), Y1.2
unnamed: C28.2, D6.2 (A), D7.1 (K)
unnamed: C29.2, IC1.1 ((PCINT14/~RESET~)PC6), P5.5, R55.1
unnamed: D1.2 (A), R18.1
unnamed: D2.1 (K), Q3.3 (C)
unnamed: D2.2 (A), R40.1
unnamed: D4.2 (A), L1.1, U7.5 (Vsw)
unnamed: D5.2 (A), R52.1
unnamed: D8.2 (A), Q1.2 (C)
unnamed: IC1.4 ((PCINT18/INT0)PD2), SW5.1 (A)
unnamed: IC1.5 ((PCINT19/OC2B/INT1)PD3), SW4.1 (A)
unnamed: IC1.6 ((PCINT20/XCK/T0)PD4), SW4.3 (B), SW5.3 (B)
unnamed: IC1.12 ((PCINT22/OC0A/AIN0)PD6), SW3.2
unnamed: IC1.13 ((PCINT23/AIN1)PD7), SW2.1
unnamed: P1.2 (D-), U9.16 (USBDM)
unnamed: P1.3 (D+), U9.15 (USBDP)
unnamed: P7.3, RV1.2
unnamed: P7.4, U11.1 (QB)
unnamed: P7.6, U11.3 (QD)
unnamed: P7.11, U11.4 (QE)
unnamed: P7.12, U11.5 (QF)
unnamed: P7.13, U11.6 (QG)
unnamed: P7.14, U11.7 (QH)
unnamed: P7.15, R56.1
unnamed: Q1.1 (B), R6.1
unnamed: Q1.3 (E), R4.1, U2.1 (SNS)
unnamed: Q2.2 (B), R35.2
unnamed: Q2.3 (C), R36.1, R39.1
unnamed: Q3.2 (B), R38.1
unnamed: R6.2, U2.7 (CC)
unnamed: R18.2, U2.5 (STAT)
unnamed: R19.1, R20.2, U2.4 (TS)
unnamed: R21.1, R32.2, U3.6 (-)
unnamed: R21.2, U3.1, U3.2 (-)
unnamed: R22.1, R29.2, U3.5 (+)
unnamed: R23.1, R24.1, R25.1, R34.2, U3.9 (-)
unnamed: R29.1, R30.2
unnamed: R32.1, R33.2
unnamed: R35.1, R38.2, U3.14
unnamed: R36.2, U3.8
unnamed: R37.1, U2.2 (BAT)
unnamed: R41.2, U6.2 (R)
unnamed: R44.1, R45.2
unnamed: R45.1, R46.2
unnamed: R48.2, R51.1, U7.2 (FB), U10.5 (PA0)
unnamed: R50.2, U10.6 (PW0)
PWM: C28.1, IC1.11 ((PCINT21/OC0B/T1)PD5)
PWM_Iset: IC1.16 ((PCINT2/OC1B/~SS~)PB2), R3.2
PWM_Vset: IC1.15 ((PCINT1/OC1A)PB1), R26.2
Pot: IC1.24 ((PCINT9/ADC1)PC1), R57.1, R58.2, R59.2, U10.1 (~CS)
Reset: C29.1, P2.1, U9.2 (DTR)
Rx: IC1.2 ((PCINT16/RXD)PD0), P2.3, U9.1 (TXD)
SCK: IC1.19 ((PCINT5/SCK)PB5), P5.3, U10.2 (SCK), U11.11 (SRCLK)
SCL: IC1.28 ((PCINT13/SCL/ADC5)PC5), P6.2, R54.1, U1.4 (SCL)
SDA: IC1.27 ((PCINT12/SDA/ADC4)PC4), P6.3, R53.1, U1.3 (SDA)
Tx: IC1.3 ((PCINT17/TXD)PD1), P2.2, U9.5 (RXD)
VEE: C30.2, D7.2 (A), R41.1, U6.3 (V-)
Vboost: C4.1, C6.2, C24.1, C25.1, D4.1 (K), R1.2, R7.2, R8.2, R9.2, R10.2, R11.2, R12.2, R13.2, R14.2, R15.2, R16.2, R22.2, R51.2, U3.4 (V+), U4.4 (VC)

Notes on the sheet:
Current sense resistor R4 = Vsns/Icharge with Vsns = 125 mV ==> Icharge = 625 mA
6 - 8.4 V
1.46 - 2.05 V
677 uA
FTDI
DISPLAY DRIVER
Charge Pump
Battery Charging
Protected cells
5V REG
0 - 5 V
0 - 2 V
Buffer
Diff amp Gain 2
Comparator
PWM DAC
Non inv amp
Gain 4
3.33k
0 - 20 V
8 - 24 V
2.048V
3.33 k
8 - 24 V
Boost Converter
Tie TS to VCC/2 to disable temp monitoring
Tab GND
Tab OUT
github.com/ThomasVDD
Tab BAT
Vboost=1.25(1+ )
R51
(R50+Rpot)//R48
__________________
5V Calibration
R37 MANDATORY to avoid ringing and destroying the chip
VCC max = 15 V

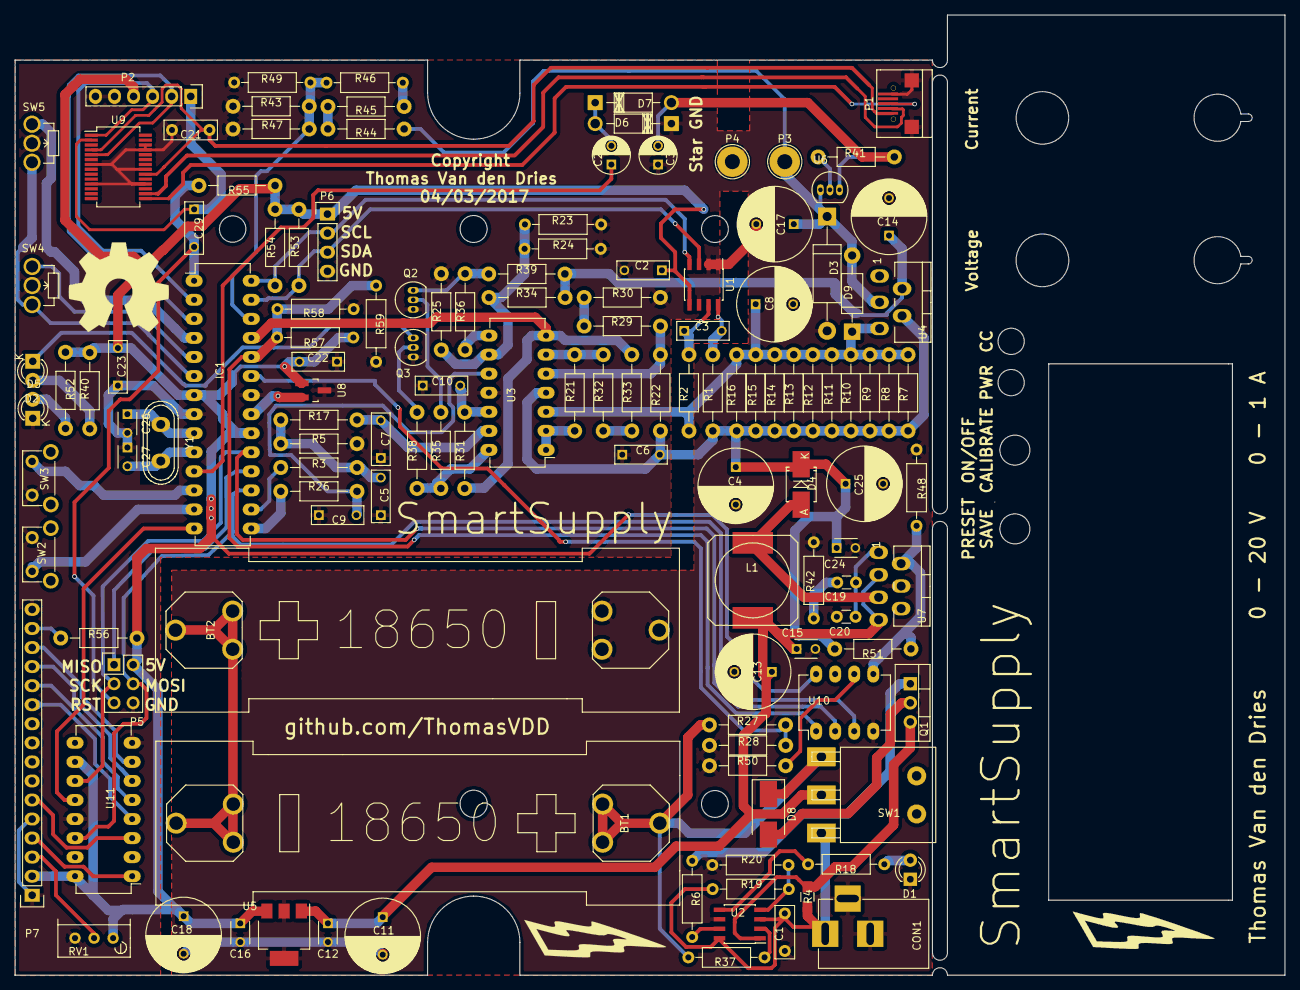
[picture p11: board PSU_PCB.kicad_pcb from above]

Board: 2 copper layers, 169.3 x 128.0 mm, 131 parts (0 on the bottom side), 84 nets.

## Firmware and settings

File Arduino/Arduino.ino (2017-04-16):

/* //==\\ ||\\  //||     //\\     ||===\\   ========  //==\\  ||    ||  ||===\\   ||===\\   ||        \\    //
 * ||     || \\// ||    //  \\    ||    ||     ||     ||      ||    ||  ||    ||  ||    ||  ||         \\  //
 * \\==\\ ||  \/  ||   //    \\   ||===//      ||     \\==\\  ||    ||  ||===//   ||===//   ||          \\//
 *     || ||      ||  //======\\  ||   \\      ||         ||  ||    ||  ||        ||        ||           //
 * \\==// ||      || //        \\ ||    \\     ||     \\==//  \\====//  ||        ||        ||======    //
 * 
 * Thomas Van den Dries
 * github.com/ThomasVDD
 * ThomasVDD on Instructables 
 * 
 * Board: arduino pro or pro mini
 * Programmer: AVR ISP / AVRISP MKII
 * For burning the bootloader: https://www.arduino.cc/en/Tutorial/ArduinoToBreadboard
 * If you accidently ordered ATMEGA328-PU instead of ATMEGA328P-PU: https://www.instructables.com/id/Bootload-an-ATmega328/
 */

/* ============================================== LIBRARIES =======================================================*/
#include<SPI.h>
#include<EEPROM.h>
#include<LiquidCrystal.h>
#include<Wire.h>
#include<INA219.h>
LiquidCrystal lcd(8);
INA219 ina219;

/* ============================================== DECLARATIONS =====================================================*/
/* make symbols for battery level*/
byte batt0[8] = {B00000, B00000, B00000, B00000, B00000, B00000, B00000,};
byte batt1[8] = {B00000, B00000, B00000, B00000, B00000, B00000, B00111,};
byte batt3[8] = {B00000, B00000, B00000, B00000, B00111, B00111, B00111,};
byte batt4[8] = {B00000, B00000, B00000, B00111, B00111, B00111, B00111,};
byte batt6[8] = {B00000, B00111, B00111, B00111, B00111, B00111, B00111,};
byte batt7[8] = {B00111, B00111, B00111, B00111, B00111, B00111, B00111,};
int batteryLine0[] = {0, 0, 1, 4, 7};
int batteryLine1[] = {3, 6, 7, 7, 7};
int batteryLevel = 0;
int batteryPin = A0;
const int numReadingsB = 10;
int readingsB[numReadingsB];
int readIndexB = 0;
int totalB = 0;
float averageB = 0;
float batteryVoltage;

int boostConverter = 0;
int boostVoltage = 0;
int potentiometerPin = A1;
int chargePump = 5;

int VoutPin = A3;
int IoutPin = A2;

int zeroButton = 6;
boolean outputOnOff = 0;

/*Rotary encoders: 0 = voltage, 1 = current*/
#define encoder0PinA  2
#define encoder1PinA  3
#define encoderPinB  4

volatile unsigned int encoder0Pos;  // keep the position of the voltage rotary encoder (0 - 50000)
volatile unsigned int encoder1Pos;  // keep the position of the current rotary encoder (0 - 50000)
int amount0 = 10;                   // changes the amount counter 0 is increased or decreased
int amount1 = 10;
unsigned long prevTime0 = 0;        // stores the previous time the interrupt was executed
unsigned long prevTime1 = 0;        // unsinged long needed for calculations with millis()!
int ticks0 = 0;                     // stores the number of times the intterupt has been called
int ticks1 = 0;
int prevEncoder0Pos = 0;            // tracks a change in value
int prevEncoder1Pos = 0;
volatile float pos0;                //keep the value of the voltage (0 - 20V mapped to 0-999)
volatile float pos1;                //keep the value of the current (0 - 1A  mapped to 0-999)

/*averages for voltage and current*/
const int numReadingsV = 20;        // number of readings to be averaged
int readingsV[numReadingsV];        // the readings from the analog input
int readIndexV = 0;                 // the index of the current reading
int totalV = 0;                     // the running total
float averageV = 0;                 // the average
float realAverageV = 0;             // the remapped average

const int numReadingsA = 20;
int readingsA[numReadingsA];
int readIndexA = 0;
int totalA = 0;
float averageA = 0;
float realAverageA = 0;

float finalA = 0;                   // holds the most accurate current measurement to be displayed
int currentRange = 320;             // the range of the current measurement, initialized at 320 mA

/* calibration & presets (pushbutton actions)*/
int currentOffset = 0;              // used to calibrate the current measurement
String readString;                  // read serial input
boolean calibrate = 1;              // tracks the current calibrate setting
String message[] = {"CALIB", "TOTAL"}; // calibration messages
float calibration[] = {0, 0};       // keeps the calibrated current
int presetButton = 7;               // switch for presets
int preset;                         // tracks the current preset
int presetV[] = {0, 0, 165, 250, 500, 999}; // voltage presets
int presetA[] = {0, 0, 330, 500, 999, 999}; // current presets
int numberOfPresets = 6;            // length of the array. First preset used for saved value

/* ============================================== SETUP =====================================================*/
void setup() {
  pinMode(10, OUTPUT);              //current setting low to keep powersupply off during initialisation
  digitalWrite(10, LOW);
  
  Serial.begin(9600);               // start serial communication
  ina219.begin();                   // initialize ina219

  analogReference(EXTERNAL);        //external voltage reference of 2.048 V
  pinMode(potentiometerPin, INPUT);
  pinMode(presetButton, INPUT);
  digitalWrite(presetButton, HIGH); //turn on pullup resistor
  pinMode(zeroButton, INPUT);
  digitalWrite(zeroButton, HIGH);   //turn on pullup resistor
  pinMode(chargePump, OUTPUT);
  analogWrite(chargePump, 127);     //50% pwm for charge pump 

  lcd.begin(16, 2);                 // initialize lcd & make battery symbols
  lcd.createChar(0, batt0);
  lcd.createChar(1, batt1);
  lcd.createChar(3, batt3);
  lcd.createChar(4, batt4);
  lcd.createChar(6, batt6);
  lcd.createChar(7, batt7);

  /* Calibrate the PWM based on the 5V rail */
  float regulator_output = 0;
  delay(100);
  for (int i = 0; i< 100; i++){                   // take 100 readings of the 5V rail
    regulator_output += analogRead(potentiometerPin);
    delay(10);
  }
  regulator_output /= 100;                         // average
  regulator_output = regulator_output * 2 * 3;     // map 1-2.048V range to corresponding value
  float regulator_error = regulator_output / 5;    // calculate error with respect to expected 5V
  setupPWM16(regulator_error);                     // initialize the 10 bit pwm
  pinMode(potentiometerPin, OUTPUT);    
  digitalWrite(potentiometerPin, HIGH);

  /* Retreive variables from EEPROM */
  encoder0Pos = EEPROMReadInt(0);                    // retreive the previous voltage value from memory
  pos0 = map(encoder0Pos, 0, 50000, 0, 999);         //map to 0 - 5 V ==> 1mA / step
  presetA[0] = map(encoder0Pos, 0, 50000, 0, 999);
  encoder1Pos = EEPROMReadInt(2);                    // retreive the previous current value from memory
  pos1 = map(encoder1Pos, 0, 50000, 0, 999);         //map to 0 - 5 V ==> 20mV / step
  presetV[0] = map(encoder1Pos, 0, 50000, 0, 999);
  //preset = EEPROMReadInt(4);                       // retreive the previous preset from memory

  //encoder 0
  pinMode(encoder0PinA, INPUT);
  digitalWrite(encoder0PinA, HIGH);       // turn on pullup resistor
  attachInterrupt(0, doEncoder0, CHANGE); // encoder pin on interrupt 0 - pin 2
  //encoder 1
  pinMode(encoder1PinA, INPUT);
  digitalWrite(encoder1PinA, HIGH);       // turn on pullup resistor
  attachInterrupt(1, doEncoder1, CHANGE); // encoder pin on interrupt 1 - pin 3
  // common pin  
  pinMode(encoderPinB, INPUT);
  digitalWrite(encoderPinB, HIGH);       // turn on pullup resistor
  
  /* initialize all the readings to 0 */
  for (int thisReading = 0; thisReading < numReadingsV; thisReading++) {
    readingsV[thisReading] = 0;
  }
  for (int thisReading = 0; thisReading < numReadingsA; thisReading++) {
    readingsA[thisReading] = 0;
  }
  for (int thisReading = 0; thisReading < numReadingsB; thisReading++) {
    readingsB[thisReading] = 0;
  }

  /* Show welcome message */
  lcd.setCursor(0, 0);
  lcd.print("  SmartSupply");
  lcd.setCursor(0, 1);
  lcd.print("   ThomasVDD");
  delay(2000);

  /* setup 16x2 lcd display:
     ------------------
     |SET 0.00V 000mA |
     |OUT 0.00V 000mA |
     ------------------
      0123456789111111
                012345
  */
  lcd.setCursor(0, 0);
  lcd.print("SET             ");
  lcd.setCursor(0, 1);
  lcd.print("OUT             ");
  lcd.setCursor(8, 0);
  lcd.print("V");
  lcd.setCursor(8, 1);  
  lcd.print("V");
  lcd.setCursor(13, 0);
  lcd.print("mA");
  lcd.setCursor(13, 1);
  lcd.print("mA");
  lcd.write(byte(0));
}

/* ============================================== LOOP =====================================================*/
/* 1) read serial data from java
 * 2) poll buttons 
 * 3) measure voltage
 * 4) measure current
 * 5) measure current with ina219
 * 6) send serial data to java
 * 7) get battery charge 
 * 8) update screen
 */

void loop() {
  /*read serial input: voltage 0-999, current 1000-1999*/
  while (Serial.available()) {
    char c = Serial.read();         //gets one byte from serial buffer
    readString += c;                //makes the string readString
    delay(2);                       //slow looping to allow buffer to fill with next character
  }
  if (readString.length() > 0) {
    int n = readString.toInt();     //convert readString into a number
    if (n >= 0 && n < 1000) {       //voltage setting
      pos1 = n;
      encoder1Pos = map(pos1, 0, 999, 0, 50000);
      if (outputOnOff){
        analogWrite16(9, pos1);
      }
    }
    else if (n >= 1000 && n <= 1999) { //current setting
      pos0 = n - 1000;
      encoder0Pos = map(pos0, 0, 999, 0, 50000);
      if (outputOnOff){
        analogWrite16(10, pos0);
      }
    }
    else if (n==9001){                // power on/off
      outputOnOff = !outputOnOff;
      if (outputOnOff){
        analogWrite16(9, pos1);
        analogWrite16(10, pos0);
      }
      else{
        analogWrite16(9, 0);
        analogWrite16(10, 0);
      }
    }
    readString = "";                //empty for next input
  }

  /* check for presets & save*/
  if (digitalRead(presetButton) == LOW) {
    delay(1000);
    //Save (long press)
    if (digitalRead(presetButton) == LOW) { 
      /*write new values to memory*/
      EEPROMWriteInt(0, encoder0Pos);
      presetA[0] = map(encoder0Pos, 0, 50000, 0, 999);
      EEPROMWriteInt(2, encoder1Pos);
      presetV[0] = map(encoder1Pos, 0, 50000, 0, 999);
      //EEPROMWriteInt(4, preset);
      lcd.setCursor(0, 0);
      lcd.print("MEM");
      delay(2500);
      lcd.setCursor(0, 0);
      lcd.print("SET ");
    }
    //Presets (short press)
    else {                                   
      preset++;
      if (preset > numberOfPresets - 1) {      //reset to preset 0
        preset = 0;
      }
      pos1 = presetV[preset];
      encoder1Pos = map(pos1, 0, 999, 0, 50000);
      if (outputOnOff){
        analogWrite16(9, pos1);
      }
      else{
        analogWrite16(9, 0);
      }
      pos0 = presetA[preset];
      encoder0Pos = map(pos0, 0, 999, 0, 50000);
      if (outputOnOff){
        analogWrite16(10, pos0);
      }
      else{
        analogWrite16(10, 0);
      }
    }
  }

  /* check for on/off and calibration*/ 
  if (digitalRead(zeroButton) == LOW){
    delay(1000);
    //CALIBRATE (long press)
    if (digitalRead(zeroButton) == LOW){
      calibrate = !calibrate;
      calibration[0] = finalA;
      lcd.setCursor(10, 1);
      lcd.print(message[calibrate]);
      delay(2500);
      lcd.setCursor(13, 1);
      lcd.print("mA");
    }
    //ON/OFF (short press)
    else{
      outputOnOff = !outputOnOff;
      if (outputOnOff){
        analogWrite16(9, pos1);
        analogWrite16(10, pos0);
      }
      else{
        analogWrite16(9, 0);
        analogWrite16(10, 0);
      }    
    }
  }

  /*Measure the voltage & average for lower noise*/
  totalV = totalV - readingsV[readIndexV];      //subtract the last reading
  readingsV[readIndexV] = analogRead(VoutPin);  //read from the sensor
  totalV = totalV + readingsV[readIndexV];      //add the reading to the total
  readIndexV = readIndexV + 1;                  //advance to the next position in the array
  if (readIndexV >= numReadingsV) {             //if we're at the end of the array...
    readIndexV = 0;                             //...wrap around to the beginning
  }
  averageV = totalV / numReadingsV;             //calculate the average
  realAverageV = averageV * 2.048 * 5 / 1023;     //map 1-2.048V range to corresponding value

  /*Measure the current & average for lower noise*/
  totalA = totalA - readingsA[readIndexA];
  readingsA[readIndexA] = analogRead(IoutPin);
  totalA = totalA + readingsA[readIndexA];
  readIndexA = readIndexA + 1;
  if (readIndexA >= numReadingsA) {
    readIndexA = 0;
  }
  averageA = totalA / numReadingsA;
  realAverageA = (averageA * 2.048 * 0.5 / 1.023);

  /*Measure the current with the INA219*/
  if (realAverageA < 300){                      // current < 320 mA can be measured with INA219
    if (realAverageA < 20 && currentRange != 40){
      currentRange = 40;
      ina219.setCalibration_40();
    }
    else if (realAverageA >= 20 && realAverageA < 50 && currentRange != 80){
      currentRange = 80;
      ina219.setCalibration_80();
    }
    else if (realAverageA >= 50 && realAverageA < 150 && currentRange != 160){
      currentRange = 160;
      ina219.setCalibration_160();
    }
    else if (realAverageA >= 150 && realAverageA < 320 && currentRange != 320){
      currentRange = 320;
      ina219.setCalibration_320();
    }    
    finalA = ina219.getCurrent_mA() - calibration[calibrate];
  }
  else{
    finalA = realAverageA - calibration[calibrate];
  }

  /* Send data to JAVA as: Voltage>Current>*/
  Serial.print(realAverageV*2);                   //send measured voltage
  Serial.print(">");
  if (finalA < 0) {                             // current lower than calibrate current
    finalA = 0;
  }
  Serial.print(finalA,2);                       //send measured current
  Serial.print(">");
  if (realAverageA > pos0 || !outputOnOff){     //send current limiting
    Serial.print("L");
  }

  /*  set the boost converter for the desired output*/
  boostVoltage = (pos1+125)*0.02; //add 125 to take the extra 2.5V into account
  //boost converter off for voltages < 5V
  if (pos1<375){
    boostConverter = 0;
  }
  else{
    boostConverter = 260 - ((36955 - 1364*boostVoltage)/(2.2*boostVoltage - 15.25))*0.0255;
    if (boostConverter > 255){
      boostConverter = 255;
    }
  }

  SPI.setClockDivider(SPI_CLOCK_DIV8);          //ensure correct clockdivider (lcd library also uses a clockdivider)
  digitalWrite(potentiometerPin, LOW);          //pull pin low to connect
  SPI.transfer(B00010011);                      //let MCP41010 know we want to set the potentiometer
  SPI.transfer(boostConverter);                 //send actual value
  digitalWrite(potentiometerPin, HIGH);         //pull pin high to disconnect

  /*write to the LCD*/ 
  lcd.setCursor(4, 0);
  if (pos1/50 < 9.994){       // <10 doesn't work because 9.995 < 10, but lcd.print(9.995,2) gives 10,00
    lcd.print(pos1 / 50 , 2);
  }
  else{
    lcd.print(pos1 / 50 , 1);
  }
  
  lcd.setCursor(4, 1);
  realAverageV *= 2; //map to 0-20V range
  if (realAverageV < 9.994){       // <10 doesn't work because 9.995 < 10, but lcd.print(9.995,2) gives 10,00
    lcd.print(realAverageV, 2);
  }
  else{
    lcd.print(realAverageV,1);
  }
  
  if (pos0 < 10){
    lcd.setCursor(11, 0);
    lcd.print("  ");      
  }
  else if (pos0 < 100){
    lcd.setCursor(12, 0);
    lcd.print(" ");  
  }
  if (finalA < 10){
    lcd.setCursor(11, 1);
    lcd.print("  ");      
  }
  else if (finalA < 100){
    lcd.setCursor(12, 1);
    lcd.print(" ");  
  }
  
  lcd.setCursor(10, 0);
  lcd.print(pos0, 0);
  lcd.setCursor(10, 1);
  lcd.print(finalA, 0);

  SOC();  // get the State Of Charge of the battery
  lcd.setCursor(15, 0);
  lcd.write(byte(batteryLine0[batteryLevel]));
  lcd.setCursor(15, 1);
  lcd.write(byte(batteryLine1[batteryLevel]));

  lcd.setCursor(0, 1);
  if (outputOnOff){
    lcd.print("OUT");
  }
  else{
    lcd.print("OFF");
  }

  delay(10);
}

/* ============================================== Functions =====================================================*/

/*interrupts*/
void doEncoder0() { //Current
  if (digitalRead(encoder0PinA) == digitalRead(encoderPinB)) {
    encoder0Pos -= amount0;
  } else {
    encoder0Pos += amount0;
  }

  if (encoder0Pos >= 60000) {   //unsigned int ==> negative numbers start from 65536
    encoder0Pos = 0;
  }
  if (encoder0Pos >= 50000) {
    encoder0Pos = 50000;
  }
  //routine to increase counter speed when rotary encoder is turned consequently
  if (millis() - prevTime0 >= 1000) { //reset ticks and amount when encoder is stationary for more than 1 second
    amount0 = 10;
    ticks0 = 0;
  }
  if (ticks0 >= 100 && millis() - prevTime0 <= 500) { //increase amount after 100 turns
    amount0 += 20;
    ticks0 = 0;
  }

  prevTime0 = millis();
  ticks0 ++;

  pos0 = map(encoder0Pos, 0, 50000, 0, 999); //map to 0 - 5 V ==> 1mA / step
  if (outputOnOff){
     analogWrite16(10, pos0);
  }
  else{
     analogWrite16(10, 0);
  }
}

void doEncoder1() { //Voltage
  if (digitalRead(encoder1PinA) == digitalRead(encoderPinB)) {
    encoder1Pos -= amount1;
  } else {
    encoder1Pos += amount1;
  }

  if (encoder1Pos >= 60000) {
    encoder1Pos = 0;
  }
  if (encoder1Pos >= 50000) {
    encoder1Pos = 50000;
  }
  if (millis() - prevTime1 >= 1000) {
    amount1 = 10;
    ticks1 = 0;
  }

  if (ticks1 >= 100 && millis() - prevTime1 <= 500) {
    amount1 += 20;
    ticks1 = 0;
  }

  prevTime1 = millis();
  ticks1 ++;

  pos1 = map(encoder1Pos, 0, 50000, 0, 999); //map to 0 - 5 V ==> 10mV / step

  if (outputOnOff){
     analogWrite16(9, pos1);
  }
  else{
     analogWrite16(9, 0);
  }
}

/* Configure digital pins 9 and 10 as 16-bit PWM outputs. */
void setupPWM16(float error) {
  DDRB |= _BV(PB1) | _BV(PB2);        /* set pins as outputs */
  TCCR1A = _BV(COM1A1) | _BV(COM1B1)  /* non-inverting PWM */
           | _BV(WGM11);              /* mode 14: fast PWM, TOP=ICR1 */
  TCCR1B = _BV(WGM13) | _BV(WGM12)
           | _BV(CS10);               /* no prescaling */
  ICR1 = error*0.996;                       /* TOP counter value = 1000; +/- 10 bit resolution @ 15 kHz*/
}

/* 16-bit version of analogWrite(). Works only on pins 9 and 10. */
void analogWrite16(uint8_t pin, uint16_t val)
{
  switch (pin) {
    case  9: OCR1A = val; break;
    case 10: OCR1B = val; break;
  }
}

/* EEPROM write and read functions*/
//This function will write a 2 byte integer to the eeprom at the specified address and address + 1
void EEPROMWriteInt(int p_address, int p_value)
{
  byte lowByte = ((p_value >> 0) & 0xFF);
  byte highByte = ((p_value >> 8) & 0xFF);

  EEPROM.write(p_address, lowByte);
  EEPROM.write(p_address + 1, highByte);
}

//This function will read a 2 byte integer from the eeprom at the specified address and address + 1
unsigned int EEPROMReadInt(int p_address)
{
  byte lowByte = EEPROM.read(p_address);
  byte highByte = EEPROM.read(p_address + 1);

  return ((lowByte << 0) & 0xFF) + ((highByte << 8) & 0xFF00);
}

/* battery measuring code
   battery voltage: 3V = empty, 4.2V = full ; 5 steps ==> 0.3V / step
   5 steps: 3V, 3.3V, 3.6V, 3.9V, 4.2V
*/
void SOC()
{
  totalB = totalB - readingsB[readIndexB];      //subtract the last reading
  readingsB[readIndexB] = analogRead(batteryPin);//read from the sensor
  totalB = totalB + readingsB[readIndexB];      //add the reading to the total
  readIndexB = readIndexB + 1;                  //advance to the next position in the array
  if (readIndexB >= numReadingsB) {             //if we're at the end of the array...
    readIndexB = 0;                             //...wrap around to the beginning
  }
  averageB = totalB / numReadingsB;             //calculate the average
  batteryVoltage = averageB * 2.048 * 4.09 / 1024;   //map 1-2.048V range to corresponding value: (2.2k + 8.8k)/2.2k = 4.09
  if (batteryVoltage >= 8.2) {
    batteryLevel = 4;
  }
  else if (batteryVoltage >= 7.6) {
    batteryLevel = 3;
  }
  else if (batteryVoltage >= 7.2) {
    batteryLevel = 2;
  }
  else if (batteryVoltage >= 6.6) {
    batteryLevel = 1;
  }
  else {
    batteryLevel = 0;
  }
}

/* ============================================== REFERENCES =====================================================*/
/* References
   Rotary encoder: http://playground.arduino.cc/Main/RotaryEncoders#Example14
   16 bit PWM: http://arduino.stackexchange.com/questions/12718/increase-pwm-bit-resolution
   Smoothing: https://www.arduino.cc/en/Tutorial/Smoothing
   LCD 74HC595: http://playground.arduino.cc/Main/LiquidCrystal
   Serial read: http://forum.arduino.cc/index.php?topic=80254.0
   EEPROM: http://forum.arduino.cc/index.php?topic=37470.0
   INA219: ADAFRUIT library
*/

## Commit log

2017-04-07 Changed Arduino and Java code to work with 20V instead of 10V
    [Sensordata.csv]
2017-04-08 Small schematic fixes + added backpanel design
    [BOM.ods, BackPanel.0002.ipt, BackPanel.dxf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]
2017-04-08 Code adapted for 20V version
2017-04-09 Updated BOM
    [BOM.ods, PSU_PCB.kicad_pcb, PSU_PCB.sch]
2017-04-10 Added calibration for the 5V voltage regulator
2017-04-12 Added pictures
    [Sensordata.csv]
2017-04-13 Changed battery monitor resistors
    [PSU_PCB.kicad_pcb, PSU_PCB.sch]
2017-04-14 Added auto calibration
2017-04-14 Added autocalibration resistors
    [BOM.ods, PSU_PCB.kicad_pcb, PSU_PCB.sch]
2017-04-17 Added resistor tolerance
    [PSU_PCB.sch]
2017-04-22 Small fix
    [PSU_PCB.kicad_pcb, Sensordata.csv]
2017-05-08 Added protection resistor to charging circuitry
    [BOM.ods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]
2017-05-13 Fixed typo
    [Sensordata.csv]
2017-05-16 Added aliexpress prices
    [BOM.ods]
2017-05-25 Small BOM optimisation
    [BOM.ods, PSU_PCB.kicad_pcb, PSU_PCB.sch]
2017-05-26 Esthetic change
    [PSU_PCB.kicad_pcb]
2017-12-19 Updated INA219 library
    [PSU_PCB.kicad_pcb, Sensordata.csv]

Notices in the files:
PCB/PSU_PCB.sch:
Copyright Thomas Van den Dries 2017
